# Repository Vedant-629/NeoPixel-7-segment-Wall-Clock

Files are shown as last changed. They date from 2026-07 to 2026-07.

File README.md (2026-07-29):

# NeoPixel-7-segment-Wall-Clock
A custom 4-digit NeoPixel 7-segment wall clock powered by an ESP8266, featuring DS3231 RTC timekeeping, automatic brightness control, and a custom-built LED display with OTA updates and Internet time sync.

# 🕐 NeoPixel Smart Wall Clock

A custom-built, Wi-Fi connected 4-digit digital wall clock using individually addressable **WS2812B NeoPixel LEDs**, an **ESP8266 NodeMCU**, and a **DS3231 RTC**. The display is built from scratch using a custom 7-segment LED mapping, with 5 LEDs per segment for a bold, vibrant look.

> Connect your phone to the clock's own Wi-Fi hotspot and configure everything — colors, brightness, Wi-Fi credentials, and timezone — from a sleek web interface. No app needed.

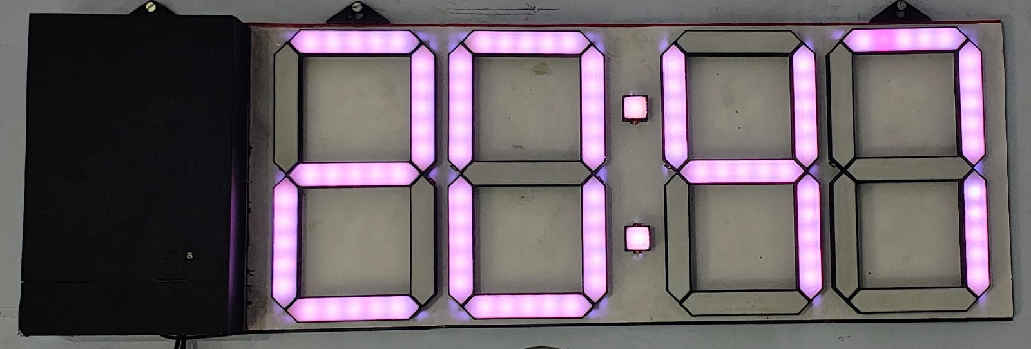
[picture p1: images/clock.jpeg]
Project Image


---

## ✨ Features

### Display
- 4-digit 7-segment clock face built from **142 individually addressable NeoPixel LEDs**
- 5 LEDs per segment, 1 LED per colon dot
- Blinking colon every second
- **Time-of-day color theming** — the display color changes automatically throughout the day:

| Period | Hours | Default Color |
|---|---|---|
| 🌅 Morning | 05:00 – 10:00 | Warm yellowish-white |
| ☀️ Noon | 10:00 – 16:00 | Soft blue |
| 🌆 Evening | 16:00 – 19:00 | Warm orange |
| 🌙 Night | 19:00 – 05:00 | Lavender |

### Automatic Brightness
- LDR continuously monitors ambient light
- Brightness **smoothly fades** between a configurable minimum and maximum — no sudden jumps
- Comfortable in both a dark bedroom and a bright office

### Web Configuration UI
Hosted directly on the ESP8266 at `http://192.168.4.1` or `http://wallclock.local` — no internet connection or app required.

- 🎨 **Color pickers** for all four time-of-day themes
- 💡 **Min/Max brightness sliders**
- 📡 **Wi-Fi credentials** input (SSID + password)
- 🌍 **Timezone selector** — 34 common UTC offsets, IST pre-selected
- ⚡ **OTA firmware update** — drag and drop a `.bin` file, no USB cable needed after initial flash
- 🕐 **Live clock** on the page with an NTP sync badge
- All settings **saved to EEPROM** and survive power cycles

### NTP Time Sync
- Clock connects to your home Wi-Fi in the background while the config hotspot stays up
- Syncs time from `pool.ntp.org` automatically on connect
- Updates the DS3231 RTC from NTP — RTC keeps time accurately even if Wi-Fi drops
- **Re-syncs every 6 hours** automatically
- Manual **Sync Now** button in the web UI
- Auto-reconnects and retries every 60 seconds if Wi-Fi drops

---

## 🔧 Hardware

| Component | Quantity | Purpose |
|---|---|---|
| ESP8266 NodeMCU v1.0 | 1 | Main controller |
| WS2812B NeoPixel LEDs | 142 | 7-segment display |
| DS3231 RTC module | 1 | Accurate timekeeping |
| LDR (photoresistor) | 1 | Ambient light sensing |
| 10kΩ resistor | 1 | LDR voltage divider |
| 470Ω resistor | 1 | NeoPixel data line |
| 1000µF capacitor | 1 | Power supply decoupling |
| 5V power supply | 1 | LED + controller power (3A+ recommended) |

### Wiring

```
ESP8266 Pin   →   Component
─────────────────────────────
D5            →   NeoPixel DATA IN (via 470Ω)
A0            →   LDR (voltage divider with 10kΩ to GND)
D1 (SCL)      →   DS3231 SCL
D2 (SDA)      →   DS3231 SDA
3.3V          →   DS3231 VCC
GND           →   DS3231 GND, LDR divider GND
5V (external) →   NeoPixel +5V
GND (shared)  →   NeoPixel GND
```

> ⚠️ Do not power 142 NeoPixels from the ESP8266's 3.3V pin. Use a dedicated 5V supply and share the GND.

---

## 🏗️ System Architecture

```
                    ┌─────────────────────────────┐
                    │         ESP8266              │
                    │                             │
  DS3231 ──I2C──►  │  RTC reader                 │
                    │  ├─ NTP sync (SNTP)         │──► NeoPixel Strip (D5)
  LDR ────ADC────►  │  ├─ Brightness control      │    142 × WS2812B
                    │  ├─ Segment mapper           │
  Home Router ───►  │  └─ Web server :80          │
  (optional)        │                             │
                    │  AP: WallClock (always on)  │◄── Browser / Phone
                    └─────────────────────────────┘
```

**Dual Wi-Fi mode (`WIFI_AP_STA`):** The clock always broadcasts its own `WallClock` hotspot for configuration while simultaneously connecting to your home router for NTP.

---

## 💾 Firmware

### Libraries Required

Install via Arduino Library Manager:

| Library | Version |
|---|---|
| Adafruit NeoPixel | Latest |
| RTClib (Adafruit) | Latest |

Built into the ESP8266 Arduino core (no install needed):
`ESP8266WiFi` · `ESP8266WebServer` · `ESP8266mDNS` · `DNSServer` · `EEPROM` · `time.h`

### Arduino IDE Board Settings

| Setting | Value |
|---|---|
| Board | NodeMCU 1.0 (ESP-12E Module) |
| Flash Size | 4MB (FS: 2MB, OTA: ~1019KB) |
| CPU Frequency | 80 MHz |
| Upload Speed | 115200 |

### Segment Layout

The 31 logical segments map to 142 physical LEDs:

```
 Digit 0    Digit 1   Colon   Digit 2    Digit 3
┌──────┐   ┌──────┐   ●●    ┌──────┐   ┌──────┐
│  7×5 │   │  7×5 │         │  7×5 │   │  7×5 │
│  LEDs│   │  LEDs│         │  LEDs│   │  LEDs│
└──────┘   └──────┘         └──────┘   └──────┘
  (35)       (35)    (2)      (35)       (35)
```

Each digit uses the standard 7-segment pattern (`a`–`g`), with 5 NeoPixels per segment chained in a single addressable strip.

### Key Design Decisions

- **Modular architecture** — display rendering, segment mapping, RTC comms, brightness control, web server, and NTP are all independent functions
- **Non-blocking loop** — Wi-Fi connection, NTP sync, and brightness ramp all use state machines so nothing stalls the display
- **EEPROM magic byte** — settings struct versioning detects firmware upgrades and re-applies factory defaults automatically

---

## 🌐 Web Interface

1. On your phone or laptop, connect to Wi-Fi: **`WallClock`** (password: `clockwifi`)
2. Open `http://192.168.4.1` — the config page loads immediately (captive portal redirects automatically on most phones)

### Sections

**Colors & Brightness** — Pick colors for each time period; set LDR brightness floor and ceiling. Hit **Save**.

**Wi-Fi & NTP** — Enter your home Wi-Fi SSID, password, and timezone. Hit **Connect & Sync**. The clock connects in the background; the status badge updates live every 3 seconds. Use **Sync Time Now** to force an immediate NTP update.

**OTA Firmware Update** — In Arduino IDE, go to `Sketch → Export Compiled Binary`. Upload the `.bin` file from this page. A progress bar tracks the upload; the clock reboots automatically when done.

---

## ⚙️ Configuration Reference

| EEPROM Setting | Default | Range |
|---|---|---|
| Morning color | `#FFF0B4` (warm white) | Any RGB |
| Noon color | `#0064FF` (blue) | Any RGB |
| Evening color | `#FF7828` (orange) | Any RGB |
| Night color | `#B48CFF` (lavender) | Any RGB |
| Min brightness | 10 | 1 – 100 |
| Max brightness | 150 | 50 – 255 |
| Timezone offset | +330 min (IST) | −720 to +840 |
| Wi-Fi SSID | *(empty)* | Up to 32 chars |
| Wi-Fi Password | *(empty)* | Up to 64 chars |

> Settings survive power cycles. Flashing new firmware resets to defaults only if the EEPROM magic byte changes (i.e. the settings struct was extended).

---

## 🖨️ Mechanical Design

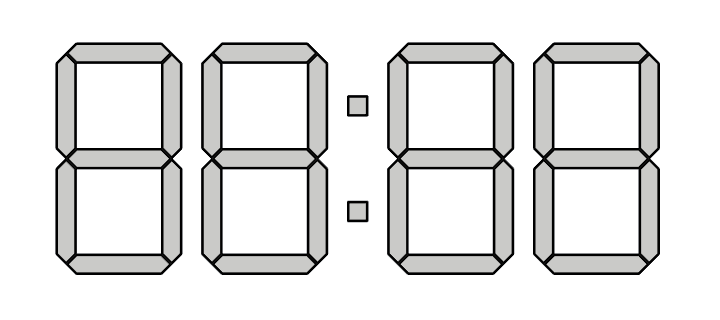
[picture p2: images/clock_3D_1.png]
Project Image


The enclosure mounts the LED strip in a 3D-printed frame designed in **Fusion 360**, with channels to diffuse each segment individually.

---

## 🔨 Assembly

1. Print or fabricate the enclosure and segment dividers
2. Cut and wire the NeoPixel strip per the segment map (see `docs/segment_wiring.pdf`)
3. Mount the DS3231 and ESP8266 on a perfboard or custom PCB
4. Wire the LDR voltage divider to `A0`
5. Flash the firmware via USB (`WallClock_WebConfig_NTP.ino`)
6. Power up, join the `WallClock` hotspot, and configure via the web UI
7. Future updates can be pushed wirelessly via the OTA page

---

## 📸 Results

Project Image

---

## 🔮 Future Improvements

- [ ] Alarm and countdown timer via web UI
- [ ] Temperature/humidity display mode (DHT22)
- [ ] Multiple display animation themes (WLED-style effects)
- [ ] Date display mode (toggle with a button or gesture)
- [ ] WLED integration for advanced color palettes
- [ ] Custom PCB to replace perfboard wiring
- [ ] Brightness curve calibration per-room profile

---

## 📄 License

MIT License — see [LICENSE](LICENSE) for details.

---

*Built by [Vedant Dehankar](mailto:vedantdehankar629@gmail.com) · RCOEM, Nagpur*

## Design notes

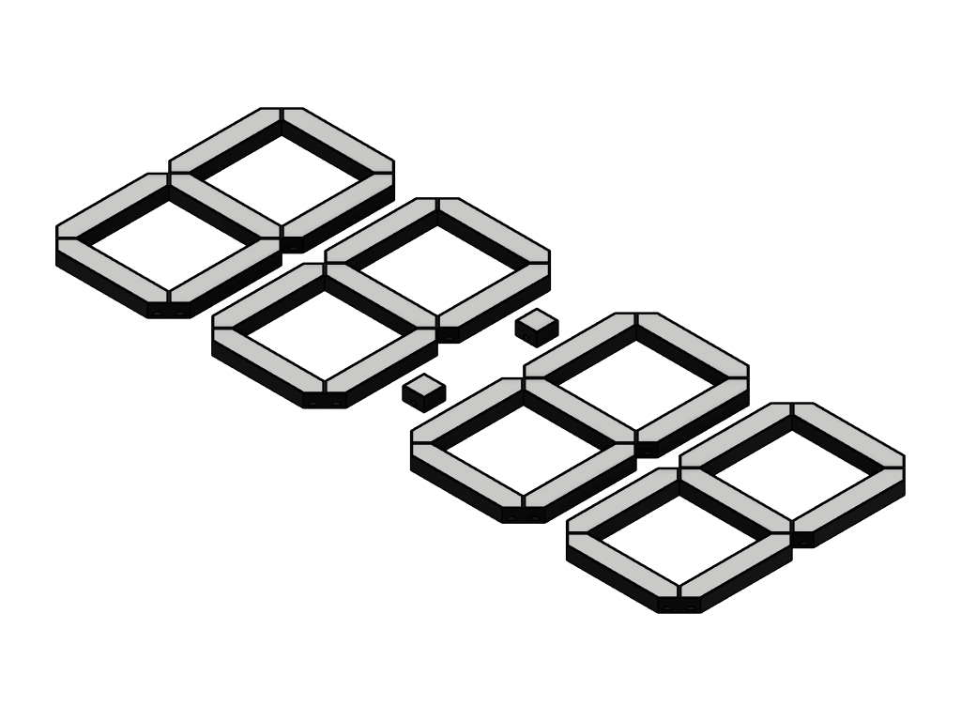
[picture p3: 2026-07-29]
images/clock_3D_2.png

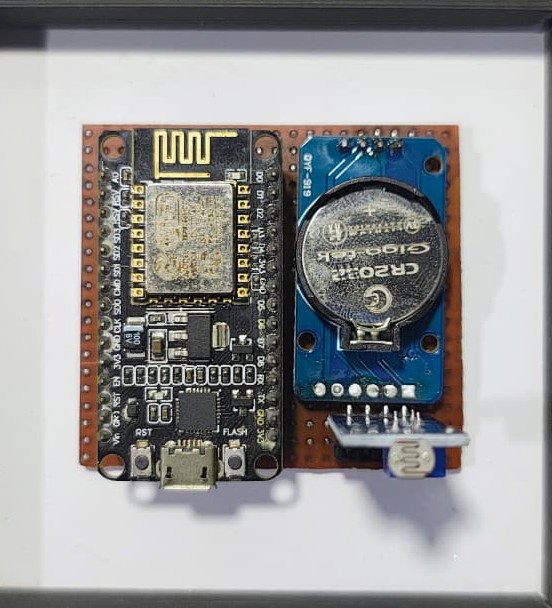
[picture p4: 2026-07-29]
images/Circuit.jpeg

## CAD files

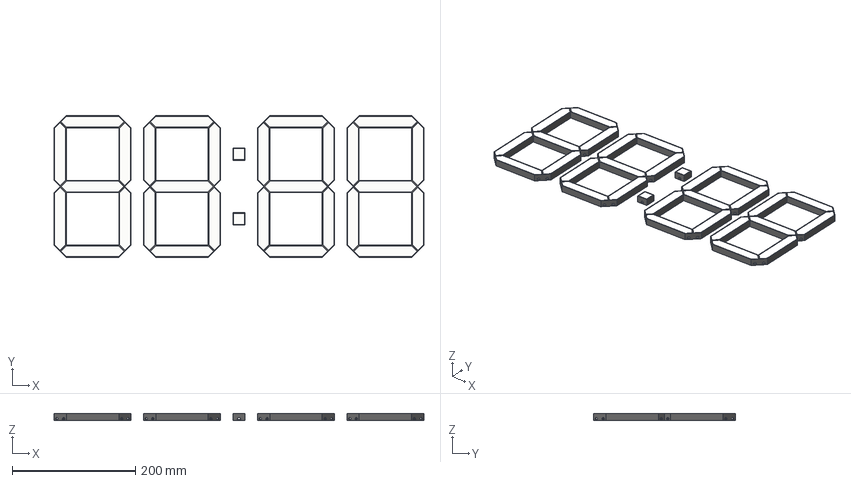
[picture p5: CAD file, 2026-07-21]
CAD/STEP/Wall_Clock.step
600.0 x 230.0 x 12.0 mm

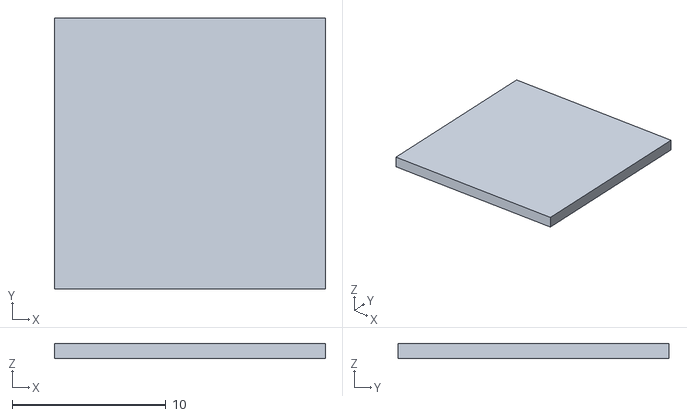
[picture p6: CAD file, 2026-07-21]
CAD/STL/Colon_Cover.stl
17.6 x 17.6 x 1.00

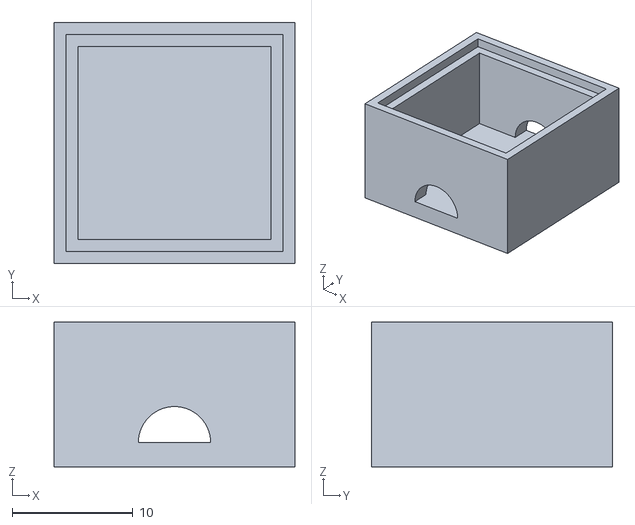
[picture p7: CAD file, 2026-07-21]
CAD/STL/Colon_Base.stl
20.0 x 20.0 x 12.0

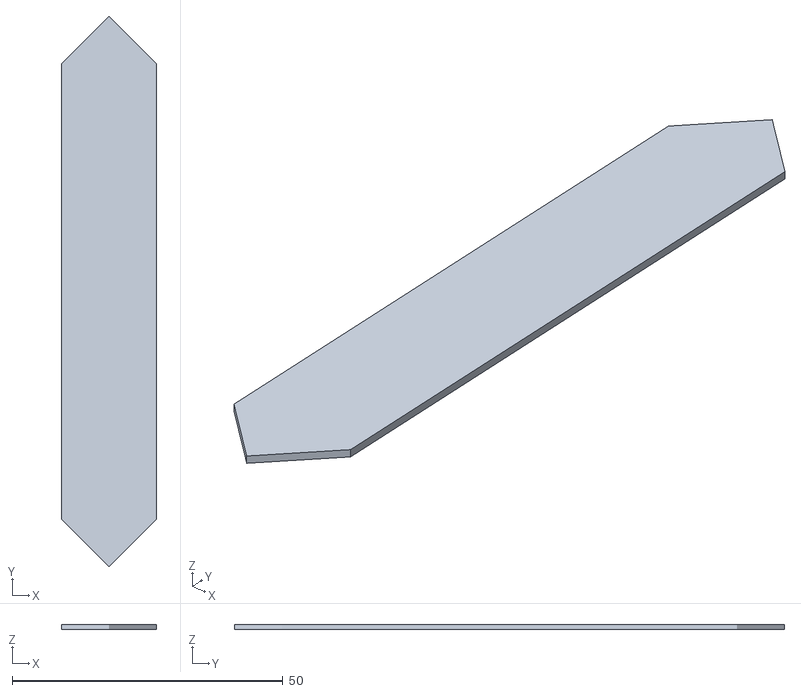
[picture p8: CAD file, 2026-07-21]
CAD/STL/Segment_Cover.stl
17.6 x 101.6 x 1.00

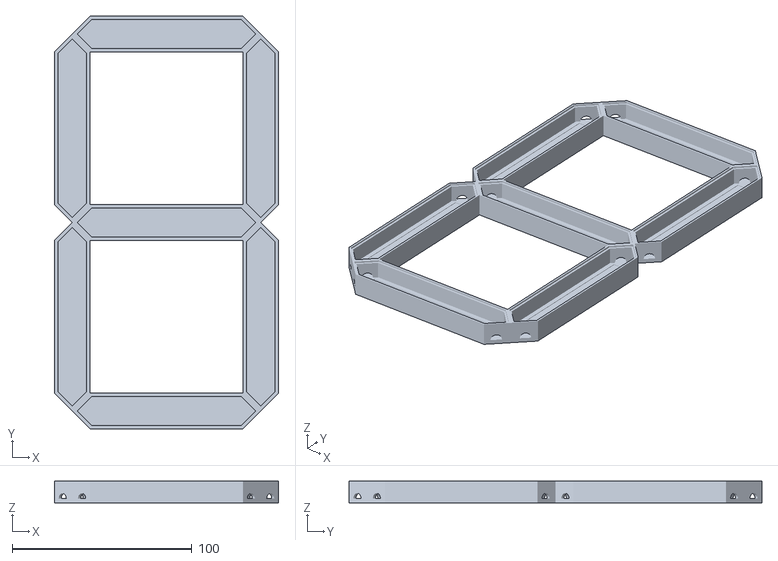
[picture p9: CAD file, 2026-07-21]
CAD/STL/Segment_Base.stl
125.0 x 230.0 x 12.0

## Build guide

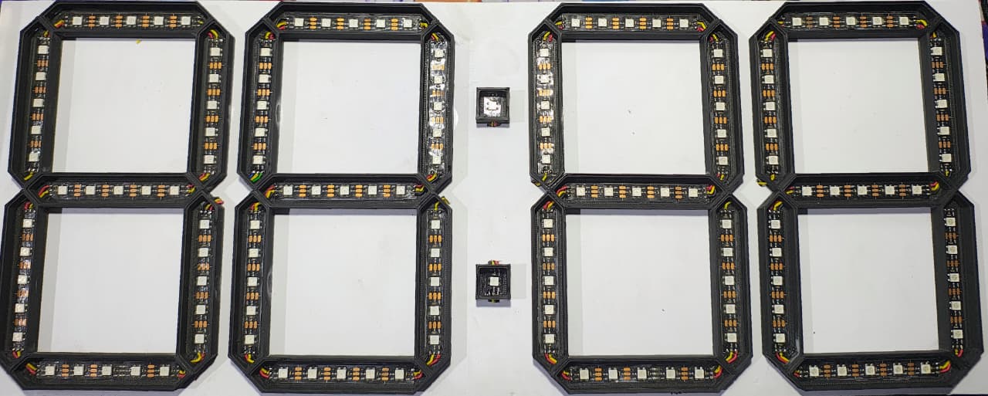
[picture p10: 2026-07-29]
images/clock_assembled.jpeg

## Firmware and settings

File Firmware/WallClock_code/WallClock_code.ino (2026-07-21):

/*
 * ╔══════════════════════════════════════════════════════════════════╗
 * ║       NeoPixel Smart Wall Clock  —  v2  (NTP Edition)           ║
 * ╠══════════════════════════════════════════════════════════════════╣
 * ║  All original features kept. New additions:                     ║
 * ║  ✦ AP mode  (SSID: WallClock  |  Pass: clockwifi)              ║
 * ║  ✦ Web UI at 192.168.4.1 / wallclock.local                     ║
 * ║    • Color pickers for Morning / Noon / Evening / Night         ║
 * ║    • Min / Max brightness sliders                               ║
 * ║    • Wi-Fi credentials + timezone selector → NTP auto-sync     ║
 * ║    • Manual "Sync Now" button                                   ║
 * ║    • Auto-reconnect + periodic re-sync every 6 hours           ║
 * ║    • OTA firmware upload with progress bar                      ║
 * ║    • Live clock on the page with NTP badge                      ║
 * ║  ✦ All settings saved to EEPROM (survive power cycles)         ║
 * ╠══════════════════════════════════════════════════════════════════╣
 * ║  Required libraries (Arduino Library Manager):                  ║
 * ║    Adafruit NeoPixel  |  RTClib                                 ║
 * ║  Built into the ESP8266 core — no install needed:              ║
 * ║    ESP8266WiFi  ESP8266WebServer  ESP8266mDNS  DNSServer        ║
 * ║    EEPROM  time.h (SNTP)                                        ║
 * ╚══════════════════════════════════════════════════════════════════╝
 */

#include <Adafruit_NeoPixel.h>
#include <Wire.h>
#include <RTClib.h>
#include <ESP8266WiFi.h>
#include <ESP8266WebServer.h>
#include <ESP8266mDNS.h>
#include <DNSServer.h>
#include <EEPROM.h>
#include <time.h>       // SNTP / configTime() / time()

// ═══════════════════════════════════════════════════════════
//  Pin & Segment Constants  (unchanged)
// ═══════════════════════════════════════════════════════════
#define LED_PIN       D5
#define NUM_SEGMENTS  31
#define LEN_NORMAL     5
#define LEN_COLON      1
#define LDR_PIN       A0

// ═══════════════════════════════════════════════════════════
//  Access-Point Credentials
// ═══════════════════════════════════════════════════════════
const char* AP_SSID = "WallClock";
const char* AP_PASS = "clockwifi";     // must be ≥ 8 chars

// ═══════════════════════════════════════════════════════════
//  EEPROM Layout
//  MAGIC changed to 0xAD → forces factory-reset on first boot
//  after flashing so new WiFi / timezone fields are initialised.
// ═══════════════════════════════════════════════════════════
#define EEPROM_SIZE  128
#define MAGIC_BYTE   0xAD

struct ClockSettings {
  uint8_t  magic;
  // ── colors ──
  uint8_t  mrR, mrG, mrB;   // Morning
  uint8_t  noR, noG, noB;   // Noon
  uint8_t  evR, evG, evB;   // Evening
  uint8_t  niR, niG, niB;   // Night
  // ── brightness ──
  uint8_t  minBr, maxBr;
  // ── network ──
  int16_t  tzOffset;         // UTC offset in minutes  (IST = 330)
  char     wifiSSID[33];     // max 32 chars + '\0'
  char     wifiPass[65];     // max 64 chars + '\0'
};  // 115 bytes — safely within EEPROM_SIZE=128

ClockSettings cfg;

// ═══════════════════════════════════════════════════════════
//  Runtime State
// ═══════════════════════════════════════════════════════════
int           currentBrightness  = 120;

// WiFi state machine
bool          wifiConnecting     = false;
bool          wifiConnected      = false;
unsigned long wifiConnectStart   = 0;
unsigned long lastWifiRetry      = 0;
#define WIFI_CONNECT_TIMEOUT_MS  15000UL   // 15 s per attempt
#define WIFI_RETRY_INTERVAL_MS   60000UL   // retry every 60 s on failure

// NTP state machine
bool          ntpSyncing         = false;
bool          ntpSynced          = false;
unsigned long ntpSyncStart       = 0;
unsigned long lastNTPSync        = 0;
char          lastSyncTimeStr[9] = "--:--:--";   // "HH:MM:SS"
#define NTP_SYNC_TIMEOUT_MS      20000UL   // 20 s to get first response
#define NTP_RESYNC_INTERVAL_MS   (6UL * 3600UL * 1000UL)   // 6 hours

// ═══════════════════════════════════════════════════════════
//  Hardware Objects
// ═══════════════════════════════════════════════════════════
RTC_DS3231         rtc;
Adafruit_NeoPixel* pStrip = nullptr;
ESP8266WebServer   server(80);
DNSServer          dnsServer;

// ═══════════════════════════════════════════════════════════
//  Segment Mapping  (unchanged from original)
// ═══════════════════════════════════════════════════════════
const char* segmentName[NUM_SEGMENTS] = {
  "a","b","c","d","e","f","g",
  "h","i","j","k","l","m","n",
  "o","p",
  "q","r","s","t","u","v","w",
  "x","y","z","A","B","C","D","E"
};
const uint8_t digitSegments[4][7] = {
  { 0, 1, 2, 3, 4, 5, 6},
  { 7, 8, 9,10,11,12,13},
  {16,17,18,19,20,21,22},
  {23,24,25,26,27,28,29}
};
const uint8_t digitPattern[10][7] = {
  {1,1,1,0,1,1,1},{0,0,1,0,0,0,1},{0,1,1,1,1,1,0},
  {0,1,1,1,0,1,1},{1,0,1,1,0,0,1},{1,1,0,1,0,1,1},
  {1,1,0,1,1,1,1},{0,1,1,0,0,0,1},{1,1,1,1,1,1,1},
  {1,1,1,1,0,1,1}
};
uint16_t segLen[NUM_SEGMENTS];
uint32_t segStart[NUM_SEGMENTS];
uint16_t TOTAL_LEDS = 0;

// ═══════════════════════════════════════════════════════════
//  EEPROM  Helpers
// ═══════════════════════════════════════════════════════════
void loadSettings() {
  EEPROM.begin(EEPROM_SIZE);
  EEPROM.get(0, cfg);
  if (cfg.magic != MAGIC_BYTE) {
    // First boot after flash — write factory defaults
    cfg.magic    = MAGIC_BYTE;
    cfg.mrR=255; cfg.mrG=240; cfg.mrB=180;   // Morning  : warm yellow-white
    cfg.noR=  0; cfg.noG=100; cfg.noB=255;   // Noon     : soft blue
    cfg.evR=255; cfg.evG=120; cfg.evB= 40;   // Evening  : orange
    cfg.niR=180; cfg.niG=140; cfg.niB=255;   // Night    : lavender
    cfg.minBr    =  10;
    cfg.maxBr    = 150;
    cfg.tzOffset = 330;                       // IST default
    memset(cfg.wifiSSID, 0, sizeof(cfg.wifiSSID));
    memset(cfg.wifiPass, 0, sizeof(cfg.wifiPass));
    EEPROM.put(0, cfg);
    EEPROM.commit();
    Serial.println(F("[EEPROM] Factory defaults written"));
  }
}

void saveSettings() {
  EEPROM.put(0, cfg);
  EEPROM.commit();
  Serial.println(F("[EEPROM] Saved"));
}

// ═══════════════════════════════════════════════════════════
//  Color Utilities
// ═══════════════════════════════════════════════════════════
String rgbToHex(uint8_t r, uint8_t g, uint8_t b) {
  char buf[8];
  snprintf(buf, sizeof(buf), "#%02X%02X%02X", r, g, b);
  return String(buf);
}
void hexToRGB(const String& hex, uint8_t& r, uint8_t& g, uint8_t& b) {
  const char* h = hex.c_str() + (hex[0] == '#' ? 1 : 0);
  uint32_t v    = strtoul(h, nullptr, 16);
  r = (v >> 16) & 0xFF;
  g = (v >>  8) & 0xFF;
  b =  v        & 0xFF;
}

// ═══════════════════════════════════════════════════════════
//  Lightweight JSON field extractor (no ArduinoJson needed)
//  Finds "key":"value"  or  "key":number
// ═══════════════════════════════════════════════════════════
String jsonStr(const String& body, const char* key) {
  String k = String('"') + key + "\":\"";
  int i = body.indexOf(k);
  if (i < 0) return "";
  i += k.length();
  int e = body.indexOf('"', i);
  return (e > i) ? body.substring(i, e) : "";
}
long jsonNum(const String& body, const char* key) {
  String k = String('"') + key + "\":";
  int i = body.indexOf(k);
  if (i < 0) return 0;
  return body.substring(i + k.length()).toInt();
}

// ═══════════════════════════════════════════════════════════
//  Display Logic  (unchanged behaviour — colors now from cfg)
// ═══════════════════════════════════════════════════════════
void computeSegmentLayout() {
  TOTAL_LEDS = 0;
  for (uint8_t s = 0; s < NUM_SEGMENTS; s++) {
    bool col    = (segmentName[s][0]=='o' || segmentName[s][0]=='p');
    segLen[s]   = col ? LEN_COLON : LEN_NORMAL;
    segStart[s] = TOTAL_LEDS;
    TOTAL_LEDS += segLen[s];
  }
}
void lightSegment(uint8_t idx, uint32_t color) {
  for (uint16_t i = 0; i < segLen[idx]; i++)
    pStrip->setPixelColor(segStart[idx] + i, color);
}
void clearAll() {
  for (uint16_t i = 0; i < TOTAL_LEDS; i++) pStrip->setPixelColor(i, 0);
}
uint32_t getTimeColor(uint8_t hour) {
  if      (hour >=  5 && hour < 10) return pStrip->Color(cfg.mrR,cfg.mrG,cfg.mrB);
  else if (hour >= 10 && hour < 16) return pStrip->Color(cfg.noR,cfg.noG,cfg.noB);
  else if (hour >= 16 && hour < 19) return pStrip->Color(cfg.evR,cfg.evG,cfg.evB);
  else                               return pStrip->Color(cfg.niR,cfg.niG,cfg.niB);
}
void displayDigit(uint8_t didx, uint8_t num, uint32_t color) {
  for (uint8_t s = 0; s < 7; s++)
    if (digitPattern[num][s]) lightSegment(digitSegments[didx][s], color);
}
void displayTime(uint8_t hour, uint8_t minute, bool colonOn) {
  clearAll();
  uint32_t color = getTimeColor(hour);
  displayDigit(0, hour   / 10, color);
  displayDigit(1, hour   % 10, color);
  displayDigit(2, minute / 10, color);
  displayDigit(3, minute % 10, color);
  if (colonOn) {
    lightSegment(14, pStrip->Color(255,255,255));
    lightSegment(15, pStrip->Color(255,255,255));
  }
  pStrip->show();
}

// ═══════════════════════════════════════════════════════════
//  NTP  —  non-blocking state machine
// ═══════════════════════════════════════════════════════════

// Kick off an NTP sync. configTime() is non-blocking; the SNTP
// client runs in the background and time() returns the result.
void beginNTPSync() {
  long tzSec = (long)cfg.tzOffset * 60L;
  configTime(tzSec, 0, "pool.ntp.org", "time.nist.gov", "time.google.com");
  ntpSyncStart = millis();
  ntpSyncing   = true;
  ntpSynced    = false;
  Serial.println(F("[NTP] Sync started"));
}

// Called every loop iteration while ntpSyncing == true.
// Once time() returns a valid Unix timestamp, updates the RTC.
void checkNTPSync() {
  if (!ntpSyncing) return;

  time_t t = time(nullptr);
  if (t > 1000000000UL) {           // sanity: year > ~2001
    struct tm* ti = localtime(&t);  // already in local TZ from configTime
    rtc.adjust(DateTime(
      (uint16_t)(ti->tm_year + 1900),
      (uint8_t) (ti->tm_mon  + 1),
      (uint8_t)  ti->tm_mday,
      (uint8_t)  ti->tm_hour,
      (uint8_t)  ti->tm_min,
      (uint8_t)  ti->tm_sec
    ));
    ntpSyncing = false;
    ntpSynced  = true;
    lastNTPSync = millis();
    // Record the RTC time-of-sync as a readable string
    snprintf(lastSyncTimeStr, sizeof(lastSyncTimeStr),
             "%02d:%02d:%02d", ti->tm_hour, ti->tm_min, ti->tm_sec);
    Serial.printf("[NTP] RTC updated → %s\n", lastSyncTimeStr);

  } else if (millis() - ntpSyncStart > NTP_SYNC_TIMEOUT_MS) {
    ntpSyncing = false;
    Serial.println(F("[NTP] Sync timed out — will retry later"));
  }
}

// Periodic re-sync: every 6 hours if connected
void checkPeriodicNTPSync() {
  if (!wifiConnected || wifiConnecting || ntpSyncing) return;
  if (!ntpSynced) return;   // initial sync hasn't succeeded yet
  if (millis() - lastNTPSync >= NTP_RESYNC_INTERVAL_MS) {
    Serial.println(F("[NTP] Periodic re-sync"));
    beginNTPSync();
  }
}

// ═══════════════════════════════════════════════════════════
//  Wi-Fi STA  —  non-blocking state machine
// ═══════════════════════════════════════════════════════════

// Initiate a STA connection attempt (AP stays up in WIFI_AP_STA mode)
void startWifiConnect() {
  if (strlen(cfg.wifiSSID) == 0) return;
  Serial.printf("[WiFi] Connecting to '%s'...\n", cfg.wifiSSID);
  WiFi.begin(cfg.wifiSSID, cfg.wifiPass);
  wifiConnecting   = true;
  wifiConnected    = false;
  wifiConnectStart = millis();
}

// Called every loop iteration — resolves the connection attempt
void checkWiFiConnect() {
  if (!wifiConnecting) return;

  if (WiFi.status() == WL_CONNECTED) {
    wifiConnecting = false;
    wifiConnected  = true;
    lastWifiRetry  = millis();  // reset back-off timer
    Serial.print(F("[WiFi] Connected! IP: "));
    Serial.println(WiFi.localIP());
    beginNTPSync();             // kick off NTP immediately

  } else if (millis() - wifiConnectStart > WIFI_CONNECT_TIMEOUT_MS) {
    wifiConnecting = false;
    wifiConnected  = false;
    lastWifiRetry  = millis();  // wait WIFI_RETRY_INTERVAL before next attempt
    WiFi.disconnect();
    Serial.println(F("[WiFi] Timed out — will retry in 60 s"));
  }
}

// Detects if a connected link has dropped, and auto-retries
void checkWiFiHealth() {
  if (wifiConnecting) return;  // already in progress

  // Detect dropped link
  if (wifiConnected && WiFi.status() != WL_CONNECTED) {
    wifiConnected = false;
    ntpSynced     = false;
    lastWifiRetry = millis();
    Serial.println(F("[WiFi] Link lost — will retry in 60 s"));
  }

  // Auto-retry if credentials are saved but not connected
  if (!wifiConnected && strlen(cfg.wifiSSID) > 0) {
    if (millis() - lastWifiRetry >= WIFI_RETRY_INTERVAL_MS) {
      Serial.println(F("[WiFi] Retrying..."));
      startWifiConnect();
    }
  }
}

// ═══════════════════════════════════════════════════════════
//  Web Page Builder
// ═══════════════════════════════════════════════════════════
String buildPage() {
  String p;
  p.reserve(7200);

  // ── Head & Styles ──────────────────────────────────────
  p += F("<!DOCTYPE html><html lang='en'><head>"
         "<meta charset='UTF-8'>"
         "<meta name='viewport' content='width=device-width,initial-scale=1'>"
         "<title>Wall Clock Config</title><style>"
         "*{box-sizing:border-box;margin:0;padding:0}"
         "body{background:#0f0f1a;color:#ddd;"
         "font-family:'Segoe UI',Arial,sans-serif;"
         "padding:14px;max-width:460px;margin:auto}"

         "h1{color:#ffd700;font-size:1.55em;text-align:center;margin-bottom:3px}"
         "h2{font-size:.95em;color:#888;margin-bottom:10px;"
         "border-bottom:1px solid #2a2a3e;padding-bottom:5px}"
         ".sub{text-align:center;color:#555;font-size:.78em;margin-bottom:16px}"
         ".card{background:#1a1a2e;border-radius:12px;"
         "padding:14px;margin:10px 0;box-shadow:0 2px 10px #0006}"

         // live clock
         ".live{text-align:center;font-size:2.4em;font-weight:700;"
         "color:#ffd700;letter-spacing:.2em;padding:6px 0}"
         ".ntpbadge{display:inline-block;font-size:.3em;vertical-align:super;"
         "background:#143314;color:#6fff6f;padding:2px 6px;"
         "border-radius:8px;letter-spacing:0;margin-left:6px}"
         ".ntpbadge.off{background:#331414;color:#ff7070}"

         // color rows
         ".row{display:flex;align-items:center;gap:10px;margin-bottom:9px}"
         ".row label,.frow label{flex:1;font-size:.88em;line-height:1.4}"
         ".tag{display:inline-block;padding:1px 6px;border-radius:9px;"
         "font-size:.72em;margin-left:4px;vertical-align:middle}"
         ".mr{background:#332a00;color:#ffd96a}"
         ".no{background:#001f40;color:#6ab8ff}"
         ".ev{background:#331500;color:#ff9a4a}"
         ".ni{background:#180030;color:#c4a0ff}"
         "input[type=color]{width:46px;height:32px;"
         "border:2px solid #333;border-radius:7px;"
         "padding:2px;cursor:pointer;background:transparent;flex-shrink:0}"

         // sliders
         "input[type=range]{flex:1;accent-color:#ffd700;min-width:90px}"
         ".val{color:#ffd700;font-size:.88em;min-width:24px;text-align:right}"

         // text / select inputs
         ".frow{display:flex;align-items:center;gap:10px;margin-bottom:9px}"
         ".inp{flex:1;background:#111128;border:1px solid #2a2a4a;"
         "color:#ddd;padding:7px 10px;border-radius:8px;font-size:.88em;"
         "outline:none}"
         ".inp:focus{border-color:#ffd700}"
         "select.inp{cursor:pointer}"

         // net status badge
         ".netbadge{padding:7px 12px;border-radius:8px;font-size:.82em;"
         "margin-bottom:10px;display:block}"
         ".nb-gray{background:#222;color:#888}"
         ".nb-yellow{background:#332200;color:#ffd700}"
         ".nb-green{background:#103010;color:#6fff6f}"
         ".nb-red{background:#2a0808;color:#ff7070}"

         // buttons
         ".btn{display:block;width:100%;padding:11px;"
         "border:none;border-radius:10px;"
         "font-size:.97em;font-weight:700;cursor:pointer;margin-top:6px}"
         ".save{background:#ffd700;color:#0f0f1a}"
         ".save:hover{background:#e6c200}"
         ".conn{background:#1565c0;color:#fff}"
         ".conn:hover{background:#1976d2}"
         ".syncp{background:#4a148c;color:#fff;margin-top:6px}"
         ".syncp:hover:not(:disabled){background:#6a1aaf}"
         ".syncp:disabled{background:#2a1a3e;color:#555;cursor:not-allowed}"
         ".ota{background:#e94560;color:#fff;margin-top:8px}"
         ".ota:hover{background:#c03050}"
         ".ota:disabled{background:#555;cursor:not-allowed}"

         // status messages
         ".status{padding:8px 12px;border-radius:8px;"
         "margin-top:7px;font-size:.83em;display:none}"
         ".ok{background:#143314;color:#6fff6f;display:block}"
         ".er{background:#331414;color:#ff7070;display:block}"

         // OTA progress
         "#pww{background:#222;border-radius:3px;"
         "overflow:hidden;margin-top:8px;display:none;height:7px}"
         "#pw{height:7px;background:#ffd700;border-radius:3px;"
         "width:0;transition:width .2s}"
         "input[type=file]{width:100%;color:#888;font-size:.83em;padding:3px 0}"

         // eye-icon button
         ".eyebtn{background:#1a1a3a;border:1px solid #2a2a4a;color:#888;"
         "padding:7px 10px;border-radius:8px;cursor:pointer;font-size:.9em}"
         ".eyebtn:hover{color:#ddd}"

         "code{background:#222;padding:1px 5px;border-radius:4px;font-size:.85em}"
         "a{color:#ffd700}"
         "</style></head><body>");

  // ── Header ─────────────────────────────────────────────
  p += F("<h1>&#x1F553; Wall Clock</h1>"
         "<p class='sub'>Join Wi-Fi &nbsp;<b>WallClock</b>&nbsp;"
         "(pass: <b>clockwifi</b>)&nbsp; then open &nbsp;"
         "<a href='http://192.168.4.1'>192.168.4.1</a>"
         " &nbsp;or&nbsp; "
         "<a href='http://wallclock.local'>wallclock.local</a></p>");

  // ── Live Clock ─────────────────────────────────────────
  p += F("<div class='card'>"
         "<div class='live' id='clk'>--:--:--"
         "<span class='ntpbadge off' id='ntpbadge'>NTP</span>"
         "</div></div>");

  // ── Time-Based Colors ──────────────────────────────────
  p += F("<div class='card'><h2>&#x1F3A8;&nbsp; Time-Based Colors</h2>");

  p += F("<div class='row'><label>&#x1F305; Morning"
         "<span class='tag mr'>05:00–10:00</span></label>"
         "<input type='color' id='c_mr' value='");
  p += rgbToHex(cfg.mrR,cfg.mrG,cfg.mrB);
  p += F("'></div>");

  p += F("<div class='row'><label>&#x2600;&#xFE0F; Noon"
         "<span class='tag no'>10:00–16:00</span></label>"
         "<input type='color' id='c_no' value='");
  p += rgbToHex(cfg.noR,cfg.noG,cfg.noB);
  p += F("'></div>");

  p += F("<div class='row'><label>&#x1F306; Evening"
         "<span class='tag ev'>16:00–19:00</span></label>"
         "<input type='color' id='c_ev' value='");
  p += rgbToHex(cfg.evR,cfg.evG,cfg.evB);
  p += F("'></div>");

  p += F("<div class='row'><label>&#x1F319; Night"
         "<span class='tag ni'>19:00–05:00</span></label>"
         "<input type='color' id='c_ni' value='");
  p += rgbToHex(cfg.niR,cfg.niG,cfg.niB);
  p += F("'></div></div>");

  // ── Brightness ─────────────────────────────────────────
  p += F("<div class='card'><h2>&#x1F4A1;&nbsp; Auto-Brightness (LDR)</h2>");

  p += F("<div class='row'><label>&#x1F315; Max brightness"
         "&nbsp;<span style='color:#555;font-size:.8em'>(bright room)</span></label>"
         "<input type='range' id='br_max' min='50' max='255' value='");
  p += cfg.maxBr;
  p += F("' oninput=\"document.getElementById('v_max').innerText=this.value\">"
         "<span class='val' id='v_max'>");
  p += cfg.maxBr;
  p += F("</span></div>");

  p += F("<div class='row'><label>&#x1F311; Min brightness"
         "&nbsp;<span style='color:#555;font-size:.8em'>(dark room)</span></label>"
         "<input type='range' id='br_min' min='1' max='100' value='");
  p += cfg.minBr;
  p += F("' oninput=\"document.getElementById('v_min').innerText=this.value\">"
         "<span class='val' id='v_min'>");
  p += cfg.minBr;
  p += F("</span></div></div>");

  // ── Save Button  (colors + brightness) ────────────────
  p += F("<button class='btn save' onclick='doSave()'>&#x1F4BE;&nbsp; Save Colors &amp; Brightness</button>"
         "<div id='ss' class='status'></div>");
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
void loop() {
  // ── Network service (must run every iteration) ─────────
  dnsServer.processNextRequest();
  server.handleClient();
  MDNS.update();

  // ── Wi-Fi + NTP state machines ─────────────────────────
  checkWiFiConnect();       // resolve ongoing connection attempt
  checkWiFiHealth();        // detect drops + auto-retry
  checkNTPSync();           // detect NTP response + update RTC
  checkPeriodicNTPSync();   // 6-hour re-sync

  // ── Clock timers ───────────────────────────────────────
  static bool          colonState       = false;
  static unsigned long lastColonToggle  = 0;
  static unsigned long lastBrightUpdate = 0;
  static unsigned long lastDisplayUpdate= 0;
  unsigned long now = millis();

  // Smooth brightness from LDR, respecting user-set min/max
  if (now - lastBrightUpdate >= 50) {
    lastBrightUpdate = now;
    int ldr    = analogRead(LDR_PIN);                         // 0–1023
    int target = map(ldr, 0, 1023, cfg.maxBr, cfg.minBr);   // bright → dim
    target     = constrain(target, (int)cfg.minBr, (int)cfg.maxBr);
    if (abs(target - currentBrightness) > 1) {
      currentBrightness += (target > currentBrightness) ? 1 : -1;
      pStrip->setBrightness(currentBrightness);
    }
  }

  // Blink colon every 1 s
  if (now - lastColonToggle >= 1000) {
    lastColonToggle = now;
    colonState = !colonState;
  }

  // Refresh display every 500 ms
  if (now - lastDisplayUpdate >= 500) {
    lastDisplayUpdate = now;
    DateTime t = rtc.now();
    displayTime(t.hour(), t.minute(), colonState);
  }
}
